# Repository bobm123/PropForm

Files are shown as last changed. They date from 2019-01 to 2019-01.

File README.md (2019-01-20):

##  Propeller Form MKII

Scripts for making propellers for use in rubber powered model airplanes.

These OpenSCAD scripts generates a form for molding a propeller suitable for use on lightweight rubber band powered indoor model airplanes. The form is used to warp flat sheets of balsa into a curved and twisted shape needed to produce efficient propeller blades. The cover photo shows the MKI version for a 7" x 22" prop form and template for a Limited Pennyplane class model.
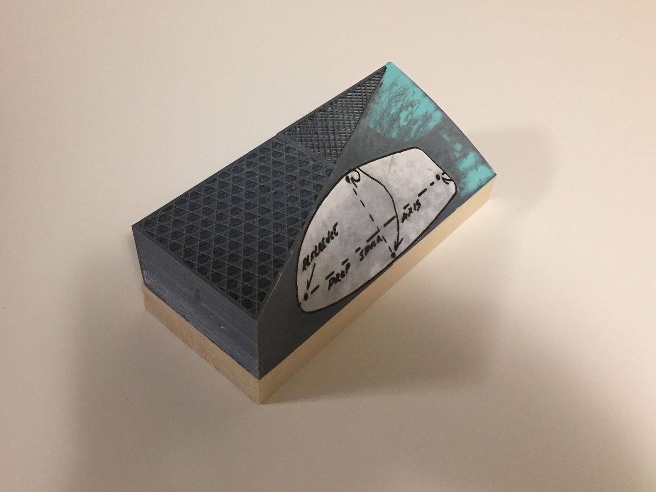
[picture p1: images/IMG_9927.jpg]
Pennyplane Prob Block


[pennyplane_block]: https://github.com/bobm123/PropForm/blob/master/images/IMG_9927.jpg

The usual procedure involves carving a wooden block for forming. This script automates that part of the process by generation such a mold from design parameters.

Details on design and construction of propellers for various endurance classes of rubber band powered model airplanes can be found on several websites, such as  https://indoornewsandviews.files.wordpress.com/2012/10/inav_121_press.pdf
Note, some competitions require that you use commercially manufactured propellers, so these scripts might not be useful there.

### Mark II Version Features

The MKII version is an attempt to improve on these by first rotating the form so the blade lies flat.
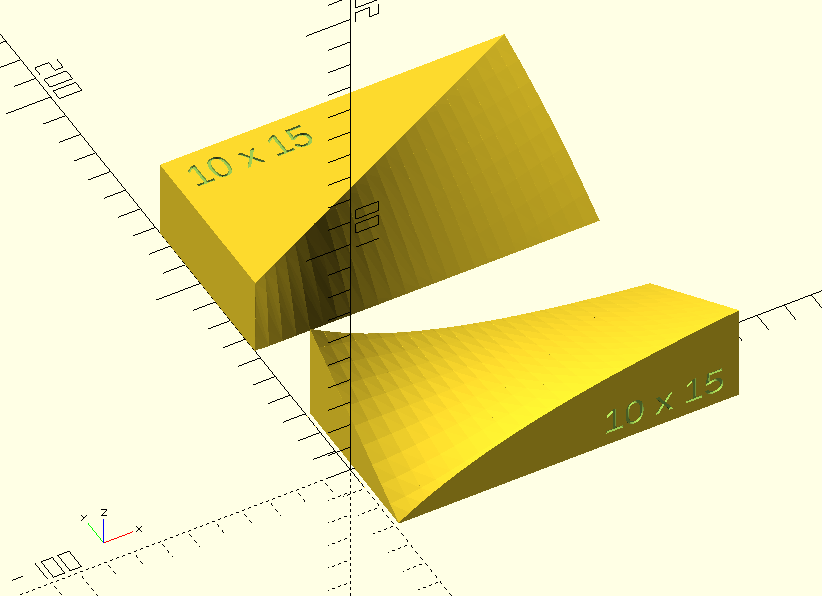
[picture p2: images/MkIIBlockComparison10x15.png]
Mark II Block vs Mark I


[MarkII_Block]: https://github.com/bobm123/PropForm/blob/master/images/MkIIBlockComparison10x15.png

As an option, the blade shape can be cutout to an approximation of the design given here:

https://ntrs.nasa.gov/archive/nasa/casi.ntrs.nasa.gov/19790015732.pdf

### OpenSCAD Version

The latest versions of OpenSCAD include an optimizer panel that allows you to change parameters without modifying code. 
![Using the Customizer] [using_the_customizer]

[using_the_customizer]: https://github.com/bobm123/PropForm/blob/master/images/CustomizerScreenshot.jpg

The development snapshots, such as OpenSCAD-2019.01.10 are available by scrolling down to the "Development Snapshots" area at http://www.openscad.org/downloads.html

The basic design parameters for a propeller are its diameter and pitch, or theoretical distance traveled in one revolution. The block width is also needed as this indirectly sets the blade's chord.

Additional options include whether the blades are flat plates or curved cross sections. Currently the script does not support other airfoil shapes, but that could be added. Finally, a parameter specifies the number of sections along the length of the blade. I suggest not increasing this too much (at least while adjusting the other parameters) as the script may become unresponsive. Values of about 50 seems like a good number here. 

Of course, other blade shapes can be used by printing a recatngular block and using it to form any shaped blanks. One common variation is to placed the blade centerline ahead of the form centerline slightly. This is sometime done so the thin blade material flexes slightly under high torque at the beginning of the motor run and possibly yields something like a variable pitch propeller.

### Larrabee Planforms

Describe the LarrabeePlanform.scad script.
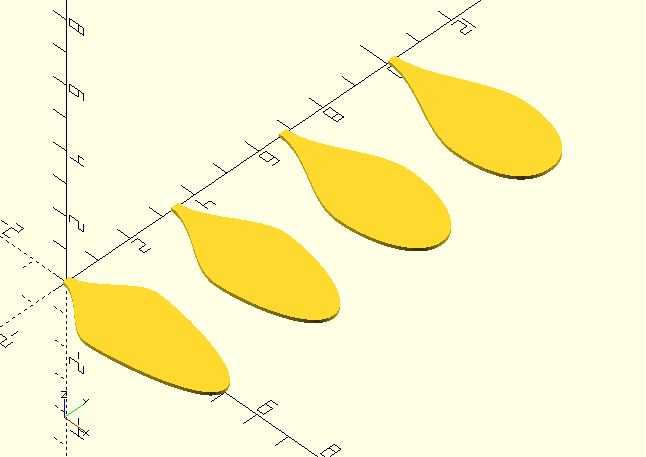
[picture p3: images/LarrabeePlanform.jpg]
Larrabee planform for Different Pitch props


[larrabbee_examples]: https://github.com/bobm123/PropForm/blob/master/images/LarrabeePlanform.jpg

### Alternate Extruder Function for OpenSCAD

Motivation: to provide additional features for the native OpenSCAD linear_transform() operation whith specific requirements for how verticies are mapped between endpoint.
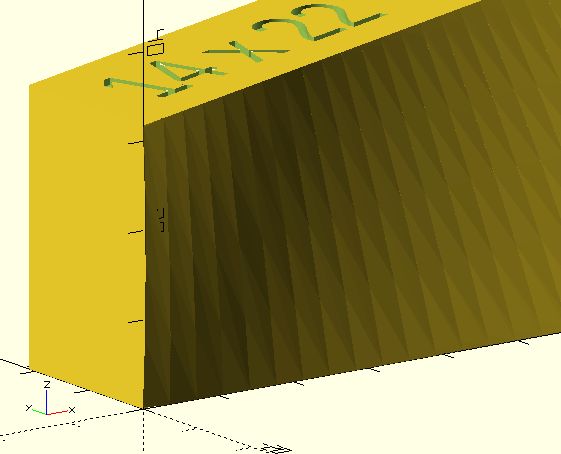
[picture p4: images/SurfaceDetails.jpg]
Surface details


[surface_details]: https://github.com/bobm123/PropForm/blob/master/images/SurfaceDetails.jpg

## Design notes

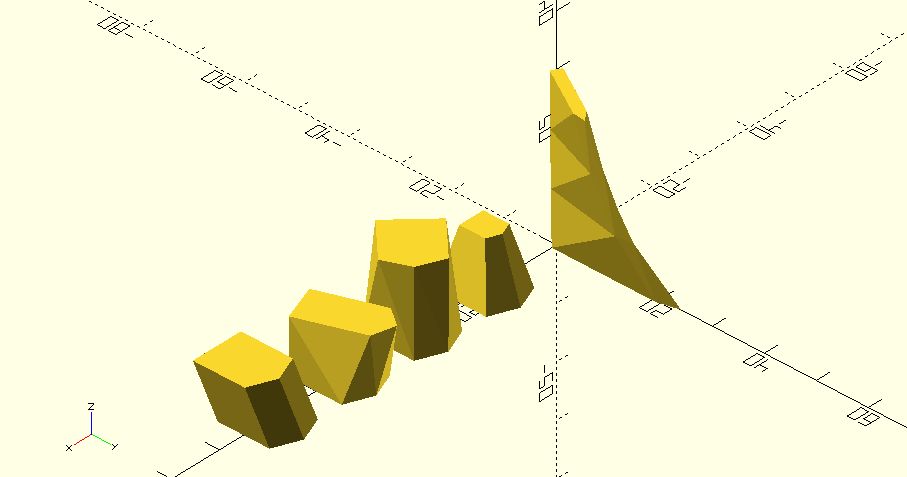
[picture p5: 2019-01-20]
images/AltExtrude-screenshot.jpg

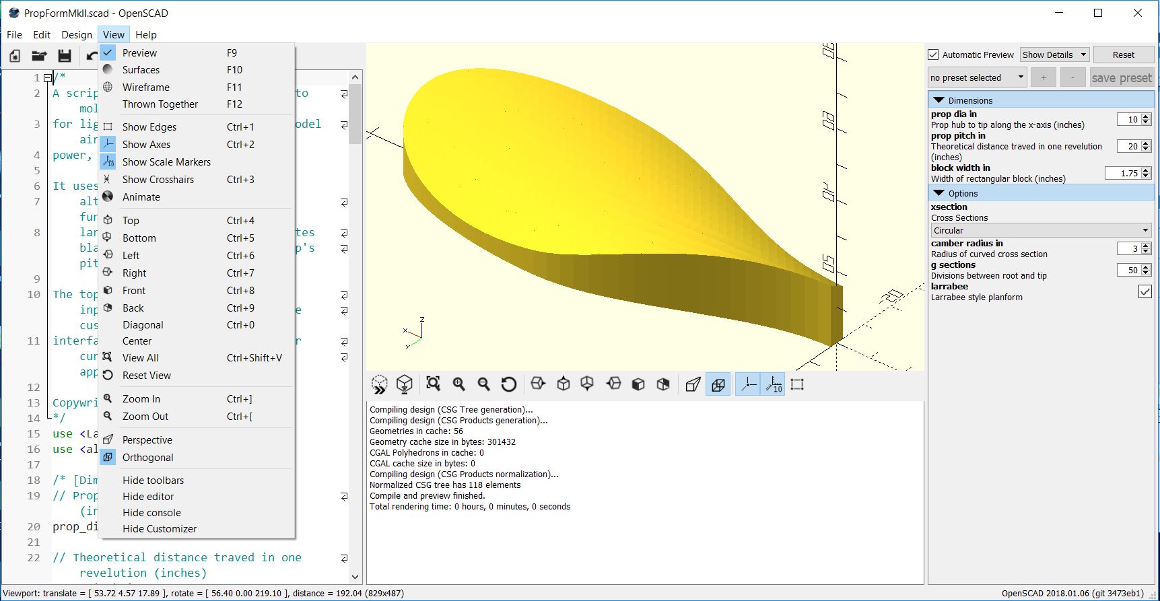
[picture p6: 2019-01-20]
images/CustomizerScreenshot.jpg

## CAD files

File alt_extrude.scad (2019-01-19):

//# Copyright (C) 2017 Robert Marchese
//
// An alternative to the standard linear extrusion operation.
//
// A list of 2D coordinates is transformed by the given parametes 
// and moved to the z=h plane. The original and transformed set of 
// points are used to generate a polyhedron.
//
// This program is available under the Creative Commons 
// Attribution-ShareAlike License; additional terms may apply. 
// 
// References:
// https://en.wikipedia.org/wiki/Transformation_matrix#Affine_transformations
// https://en.wikibooks.org/wiki/OpenSCAD_User_Manual/Primitive_Solids#polyhedron
//

// Examples
// Test points form a little house shape centered on [0,0]
points = [[-5,-5],[5,-5],[5,5],[0,7],[-5,5]];


//translate([-15,0,0]) polygon(points);

// height 10, no other transforms
//alt_extrude(points, 10);
stretch (
    points,
    transform_matrix(0, 0, [.2,2],[0,5]),
    transform_matrix(10, -10, [.2,1.5], [0,5]));
stretch (
    points,
    transform_matrix(10, -10, [.2,1.5], [0,5]),
    transform_matrix(20, -20, [.2,1.25], [0,5]));
stretch (
    points,
    transform_matrix(20, -20, [.2,1.25], [0,5]),
    transform_matrix(30, -30, [.2,1.125], [0,5]));

// height 10, top surface scaled to half size
translate([15,0,0]) alt_extrude(points, 10, 0, [.5,.5]);

// height 15, rotated 45 deg counter clockwise
translate([30,0,0]) alt_extrude(points, 15, -45, [1, 1]);

// height 10, rotated 20 deg and scaled 75% in X, 125% in Y
translate([45,0,0]) alt_extrude(points, 10, 20, [.75,1.25]);

// height 10, skewed left x=3 and down 2
translate([60,0,0]) alt_extrude(points, 10, 0, [1,1], [3,-2]);
// Examples
//

// Dot product of two vectors of length 3.
function dot(a, b) = a[0]*b[0]+a[1]*b[1]+a[2]*b[2];

// Generates a transfrom matrix from the given paramers
// h - the Z-axis value the polygon is moved to
// a - rotation angle
// s - scale factors, a vector [Sx, Sy]
// t - translation value, a vector [Tx, amd Ty]
// Returns a 3x3 matrix for the Rotation, Scale and 
// Translation (in that order)
/*
function transform_matrix(h=0, a=0, s=[1,1], t=[0,0]) = 
    [[s[0]*cos(a), -s[1]*sin(a), t[0]],
     [s[0]*sin(a),  s[1]*cos(a), t[1]],
     [          0,            0, h]];
*/
function transform_matrix(h=0, a=0, s=[1,1], t=[0,0]) =
    [[s[0]*cos(a), -s[1]*sin(a), t[0]*s[0]*cos(a)-t[1]*s[1]*sin(a)],
     [s[0]*sin(a),  s[1]*cos(a), t[0]*s[0]*sin(a)+t[1]*s[1]*cos(a)],
     [          0,            0, h]];

// Stiches together two sets of 2D polygon points seperated to for a 
// polyhedron. The two sets of points are generated by extending the
// original set into 3D (by adding a 3D coordinate, Z=1) and then
// transforming them with the two matricies, m0 and m1. 
module stretch(p2d, m0, m1) {
    n = len(p2d);

    p = [ for(i=[0:n-1]) [p2d[i][0], p2d[i][1], 1] ];

    p0 = [for(i=[0:n-1]) [dot(p[i],m0[0]), dot(p[i],m0[1]), dot(p[i],m0[2])] ];
    p1 = [for(i=[0:n-1]) [dot(p[i],m1[0]), dot(p[i],m1[1]), dot(p[i],m1[2])] ];

    bottom = [[for(i=[0:n-1]) i]];
    top    = [[for(i=[2*n-1:-1:n]) i%(2*n)]];
    sides  = [ for (i=[0:n-1]) [(0+i)%n+n,(1+i)%n+n,(1+i)%n,(0+i)%n]];
    all_faces = concat(bottom, top, sides);

    polyhedron(concat(p0, p1), all_faces);
}


// Form a polygon from the points p. The bottom surfaces is
// and n-gon defined by p while the top surface is generated
// from these by applying transforms given in the parameters
// 
//  p - The set of points forming the base of the polyhedron
//  h - The height of the polyhedron
//  ang-Rotation of the top surface around [0,0]
//  s - A vector length 2 defining the scale factors for x and Y
//  t - A vector defining the translation distance. Note, this
//      transform is applied after all of the others.
//
module alt_extrude(p, h=1, ang=0, s=[1,1], t=[0,0]) {
    stretch (
        p,
        transform_matrix(),
        transform_matrix(h+1, ang, s, t));
/*
    n = len(p);

    // Generate the transform matrix for top surface. Could be
    // 2x2, but the last column defines a skew tanslation. 
    M =[[s[0]*cos(ang), -s[1]*sin(ang), t[0]],
        [s[0]*sin(ang),  s[1]*cos(ang), t[1]],
        [            0,              0, 1]];

    // Extend coords for bottom to 3D, using z=1 (see Affine
    // Transforms reference above)
    p0 = [ for(i=[0:n-1]) [p[i][0], p[i][1], 1] ];

    // Apply transform matrix to x and y values of p0. Z value is
    // overwritten since it would be ignored for this 2D transform
    // and it is convenient to do it here.
    p1 = [for(i=[0:n-1]) [dot(p0[i],M[0]), dot(p0[i],M[1]), h+1] ];

    // Each faces is defined by a list of vertcies taken from
    // p0 and p1. The top and bottoms are all the p0 and p1
    // taken in clockwise order when looking at the final polyhedron
    // from outside. The others are two points from p0 and the 
    // corresponding 2 from p1.
    bottom = [[for(i=[0:n-1]) i]];
    top   = [[for(i=[2*n-1:-1:n]) i%(2*n)]];
    sides = [ for (i=[0:n-1]) [(0+i)%n+n,(1+i)%n+n,(1+i)%n,(0+i)%n]];
    all_faces = concat(bottom, top, sides);

    // Generate the polyhedron and translate down 1 unit to compensate
    // for offset used to expand 2D points into 3D
    translate([0,0,-1]) polyhedron(concat(p0, p1), all_faces);
*/
}

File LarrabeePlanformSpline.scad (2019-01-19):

// Approximate position of maximum Chord as a fucntion of Pd.
function CmaxPosition(Pd) = -0.07291667*Pd*Pd + 0.44166667*Pd - 0.01875;

Hinv = [
    [1.,0.,0.,0.],
    [0.,1.,0.,0.],
    [-3.,-2.,3.,-1.],
    [ 2.,1.,-2.,1.]
];

U = [for (i=[0:.05:1.05]) [1,i,i*i,i*i*i]];

Chord = 2.25;
linear_extrude(.1) {
    translate([0, Chord*0.0, 0]) larrabee_planform (5, 1.0, Chord);
    translate([0, Chord*1.5, 0]) larrabee_planform (5, 1.5, Chord);
    translate([0, Chord*3.0, 0]) larrabee_planform (5, 2.0, Chord);
    translate([0, Chord*4.5, 0]) larrabee_planform (5, 2.5, Chord);
}


module larrabee_planform(dia, Pd, Cmax) {

    cp = dia * CmaxPosition(Pd);

    c0 = [[0,Cmax/20], [cp,0], [cp,Cmax/2], [cp,0]];
    c1 = [[cp,Cmax/2], [cp,0], [dia,0], [0,-(Cmax)]];
    c2 = [[dia,0],[0,-(Cmax)], [cp,-Cmax/2], [-cp,0]];
    c3 = [[cp,-Cmax/2], [-cp,0], [0,-Cmax/20], [-cp,0]];

    path = [c0, c1, c2, c3];
    /*
    color("Blue") {
        translate([cp,0]) circle(Cmax/2, $fn=48);
        translate([dia-Cmax/6,0]) circle(Cmax/6, $fn=48);
    }
    */
    
    polygon([for(c = path) for (p = U*Hinv*c) p]);
/*
    for (c = path) {
        coef = Hinv*c;
        for (p = U*coef) {
            translate(p) circle(.05);
        }
    }
*/
}

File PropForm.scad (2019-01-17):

/*
A script for generating blocks used to mold propeller blades suitable
for light-weight rubber band power model airplanes or simmilar low
power, low RPM applications.

Copywrite 2018, Robert Marchese
*/
 
/* [Dimensions] */
// Prop hub to tip along the x-axis (inches)
prop_dia_in = 14.0;

// Theoretical distance traved in one revelution (inches)
prop_pitch_in = 22.0;

// Width of rectangular block (inches)
block_width_in = 2.5;

/* [Options] */ 
// Cross Sections
xsection="curved";  // [curved:Circular,flat:Flat]

// Radius of curcved cross section
camber_radius_in = 10.0;

// Divisions between root and tip
sections = 50;

/* [Print Options] */
show_dimensions = true;
minimal_volume = true;

/* [Hidden] */
mm = 25.4;
$fn = 192;

// convert user inputs to metric
prop_dia = prop_dia_in * mm;
prop_pitch = prop_pitch_in * mm;
block_width = block_width_in * mm;
camber_radius = camber_radius_in * mm;

// Determine the block thickness given diameter, pitch and width
// https://indoornewsandviews.files.wordpress.com/2012/10/inav_121_press.pdf
// From page 22, Indoor Props - Practice
function t_block(d, p, w) = p*w/(3.14159*d);

block_height =  t_block(prop_dia, prop_pitch, block_width);

// Fill in the basic block shape and add description
difference() {
    linear_extrude(block_height)
        polygon([[0,0],[prop_dia/2, block_width], [0, block_width]]);

    rotate([0,0, atan(2*block_width/prop_dia)]) {
        if (show_dimensions) {
            translate([10, 5, block_height-.8])
                linear_extrude(1.0) text(str(prop_dia/mm, " x ", prop_pitch/mm));
        }
        if (minimal_volume) {
            translate([0, 20, -1]) cube([prop_dia/2,block_width,block_height+2]);
        }
    }
}

// Iterate over the blade cross sections to generate the main surface
for(i=[0:sections-1]) {
    hull() {
        blade_section(i, block_width, block_height, sections, camber_radius, xsection);
        blade_section(i+1, block_width, block_height, sections, camber_radius, xsection);
    }
}


module circular_segment(R, c)
{
    // see https://en.wikipedia.org/wiki/Circular_segment
    d = sqrt(R*R-(c*c)/4);
    linear_extrude(0.1) difference() {
        translate([-d,0,0]) circle(R);
        translate([-R,0,0]) square(2*R, center=true);
    }
}


 module blade_section(i, width, height, sections, camber_rad=125, xsection)
 {
    width_i = i*width/sections;
    chord_i = sqrt(height*height+width_i*width_i);
    angle_i = atan(width_i / height);

    translate([(i/sections)*prop_dia/2,0,0]) {
        // generate and orient the circular segments
        if (xsection == "curved") {
            rotate([-angle_i,0,0]) 
                translate([0, 0, chord_i/2]) 
                    rotate([90, 0, -90]) circular_segment(camber_rad, chord_i);
        }
        // generate triangle to 'support' the circular segments
        rotate([0,-90,0]) linear_extrude(1.1) 
            polygon([[0,0], [0, width_i], [height, width_i]]);
    }      
}

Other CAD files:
PropFormMkII.scad

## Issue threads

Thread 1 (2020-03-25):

Add features common to indoor props

ceandraka, 2020-03-25:
Would like to edit to add flaring, washout, and customizing to fit on limited printer bed size

ceandraka, 2020-03-25:
I cloned repository, installed my changes, and put in a pull request, so I think this is done. New to Github, so hoping it was all done correctly.

Closed 2020-03-25.

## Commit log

2019-01-17 Add files via upload
    Original script published on thingiverse.com on 20180420, https://www.thingiverse.com/thing:2870790
    [PropForm.scad]
2019-01-17 Adds print options for text and minimal volume
    [PropForm.scad]
2019-01-18 Adds the new improved MKII version
    [PropFormMkII.scad]
2019-01-19 Adds missing dependency
    [LarrabeePlanformSpline.scad]
2019-01-19 Adds alt_extrude.scad to better control hull() behavior
    [alt_extrude.scad]
2019-01-19 Rename and refactor modules that iterate over blade sections
    [PropFormMkII.scad]
2019-01-19 Refactor to use alt_extrude.scad module
    [PropFormMkII.scad, alt_extrude.scad]
2019-01-19 Use a list comprehension to generate main surface points
    [PropFormMkII.scad]
2019-01-19 Adds to code to make curved cross section work
    [PropFormMkII.scad]
2019-01-19 Tweak the trimm geometries so P/d < 1 cases work
    [PropFormMkII.scad]
2019-01-20 Change list comprehension at line 100 so it works with current release of OpenSCAD
    [PropFormMkII.scad]
2019-01-20 Reorganized code and add some comments
    [PropFormMkII.scad]
2019-01-20 Some TODO: related to bound checking
    [PropFormMkII.scad]
2020-03-25 Update PropFormMkII.scad
    Modifications by Chuck Andraka, 2020:
    Added flaring capability. However, no adjustment is made to prop form rotation. The spar line is where the pitch is defined, so combining camber and flare may give a lower effective pitch than antici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
    Added washout capability. Washout is expressed in inches of pitch, and begins at 70% diameter, lineraly increasing washout to the specified value at the tip
    Added a spar pocket. Set to 0.5mm for a simple spar reference line, or set larger to accomodate a spar below the prop surface
    Added a printer bed size. If the diameter exceeds the bed size, then a diagonal box is used to clip. It sets the root (0 diameter)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
    [PropFormMkII.scad]
2026-10-08 Updates defaults and adds info to back of prop block
2026-10-08 Adds some documents on Larabee props
2026-10-10 Adds a sample prop .stl and the original .scad code
2026-10-11 Adds a printable blade template and flattens the block by default
    Generates a flat template for cutting blade blanks, selectable from the
    customizer alongside or instead of the block. The block's base outline is
    a top-down projection while material laid on the block follows the cambered
    surface, so a blank traced from the base comes out slightly narrow.
    Measuring rendered blocks showed that gap is driven mostly by how far the
    blade is tilted, not by the twist: at Rotation_Multiplier 1.0 the base runs
    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
2026-10-11 Puts the template back to 2mm
    0.5mm was useful while checking the outline against printed blocks, but it
    is floppy to handle. Back to something that holds its shape.
2026-10-11 Expands the README
    Adds a photo of a printed block with a balsa blank at the top, and a new
    section on printing and post processing covering adaptive layer height and
    filling the layer lines with putty. Layer lines matter more here than on
    most prints because they transfer into the balsa when the blade is formed.
    Fills in the Larrabee planform section, which was a placeholder. Traces the
    shape from Larrabee's 1979 NASA paper through Boor's and Barker's work to
    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
2026-10-11 Ignores generated STL files
    The script writes these out on every export, so they churn in git status
    for no benefit. Keeps PropForm_14x22.stl, which is committed as a sample.
2026-10-15 Replaces the larrabee flag with a plan form selector
    The default rectangular cut leaves tall spikes of material at the root and
    tip corners, where the twisted blade surface sweeps up past the ends of the
    block. They are no use for forming and make the block taller to print.
    Adds a trimmed plan form that cuts those corners back at 45 degrees, leaving
    a wall across each end of about a third of the chord, set by
    end_wall_fraction. On a 9x14 this takes the root wall from 30mm to 15mm and
    the block height from 26mm to 20mm.
    The larrabee boolean becomes a three way planform selector: full for the old
    square cut, trimmed for the octagon, larrabee for the blade outline.
    The template now follows t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
